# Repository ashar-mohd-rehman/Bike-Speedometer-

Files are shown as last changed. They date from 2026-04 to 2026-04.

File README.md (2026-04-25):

# Bike-Speedometer-
A digital speedometer for my mtb based on XIAO esp 32 s3, NEO 6M GPS module and an 1.3 inch OLED display




Let us talk about features 


- It shows the speed of the cycle (mtb)
- Distance covered from the starting point
- Trip timer which shows how long u have been riding for
- Altitude, which shows ur alt from sea level
- Today's Date
- Satellites GPS module is connected to
- And last but not the least. The Battery Percentage

  The main challenge I faced for CAD. I love cad very much but I always screw up I had to make the case two times :( I love cad but cad hates me

  **CASE**
  

  **Wiring Diagram**
  

  **Case With Components**


 pieace. peace whatever idk spelling 

**BOM**

LINK - https://docs.google.com/spreadsheets/d/1TzOF5hf8aBWl8qxK7e9dfW4KzLnE9d2bEbTf8p3DWF0/edit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

| Component | Description | Quantity | Unit Price (USD) | Total (USD) | Supplier |
|---|---|---|---|---|---|
| Seeed Studio XIAO ESP32-S3 | Main microcontroller | 1 | $9.66 | $9.66 | Robu.in |
| NEO-6M GPS Module | GPS module for position tracking | 1 | $2.70 | $2.70 | Robu.in |
| 1.3" I2C OLED Display Module | SSD1306 128x64 display | 1 | $2.90 | $2.90 | Robu.in |
| Molicel INR-18650-M35A | 3.6V 3500mAh Li-ion battery | 1 | $4.29 | $4.29 | Robu.in |
| MTS-101R Miniature Toggle Switch | SPST 2-pin power switch | 2 | $0.39 | $0.77 | Robu.in |
| 10kΩ 0.25W Metal Film Resistor | For voltage divider circuit | 10 | $0.003 | $0.03 | Robu.in |
| 24AWG Single Core Teflon Wire | Black hookup wire | 1m | $0.19 | $0.19 | Robu.in |
| M5x8mm Brass Heat-Set Inserts | For handlebar clamp mounting | 25 | $0.06 | $1.62 | Robu.in |
| M3x4mm Brass Heat-Set Inserts | For case assembly screws | 25 | $0.04 | $0.96 | Robu.in |
| Fog Lamp Clamp | Handlebar mounting clamp | 2 | $1.52 | $3.04 | Amazon |
| Allen Key Set | Allen keys | 1 | $2.57 | $2.57 | Robu.in |
| | | | **Total:** | **$35** | |

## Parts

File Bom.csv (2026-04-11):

Name | Purpose | Quantity | Total Cost (USD) | Link | Distributor
Fog Lamp Clamp | To clamp speedometer to bike | 2 | 3.04 | https://www.amazon.in/ELTRON-TURBO-Universal-Lamp-Clamp/dp/B0C9WVTJDK?s=automotive | Amazon
M5x8 mm Brass Heat set Threaded Round Insert Nut | To connect the speedometer with bike | 25 | 1.62 | https://robu.in/product/m5-x-8-mm-brass-heat-set-threaded-round-insert-nut-25-pcs/ | Robu.in
M3x4 mm Brass Heat Set Threaded Round Insert Nut | To screw top case to bottom | 25 | 0.96 | https://robu.in/product/m3-x-4-mm-brass-heat-set-knurl-threaded-round-insert-nut-25-pcs/ | Robu.in
24AWG Single core teflon wire | To make connections | 2 | 0.38 | https://robu.in/product/24awg-single-core-teflon-wire-black/ | Robu.in
10k Ohm 0.25W Metal Film Resistor | Volatge divider to check how much battery is left | 10 | 0.03 | https://robu.in/product/10k-ohm-0-25w-metal-film-resistor-pack-of-100/ | Robu.in
MTS-101R-Miniature Toggle Switch-2Pin | To switch on/off the speedometer when not in use | 2 | 0.77 | https://robu.in/product/mts-101r-miniature-toggle-switch-2pinon-off/ | Robu.in
Molicel A Grade INR-18650-M35A 3.6V 3500mAh 3C Li-ion Battery | Battery, To provide power to components | 1 | 4.29 | https://robu.in/product/molicel-inr-18650-m35a-3-6v-3500mah-3c-li-ion-battery/ | Robu.in
NEO-6M GPS Module | Global Positioning System Module. It measures speed using latitude and longitude data by connecting to various sattelites | 1 | 2.70 | https://robu.in/product/neo-6m-gps-module-with-eprom-normal-quality/ | Robu.in
1.3 Inch I2C OLED Display Module | To show speed, time, distance, and other various telemetry | 1 | 2.90 | https://robu.in/product/1-3-inch-i2c-oled-display-module-4-pin-white/ | Robu.in
Seeed Studio XIAO ESP32-S3 | MCU, It is the brain of my speedometer | 1 | 9.66 | https://robocraze.com/products/seeed-studio-xiao-esp32-s3-development-board-supports-wi-fi-bluetooth-5-0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 | Robocraze

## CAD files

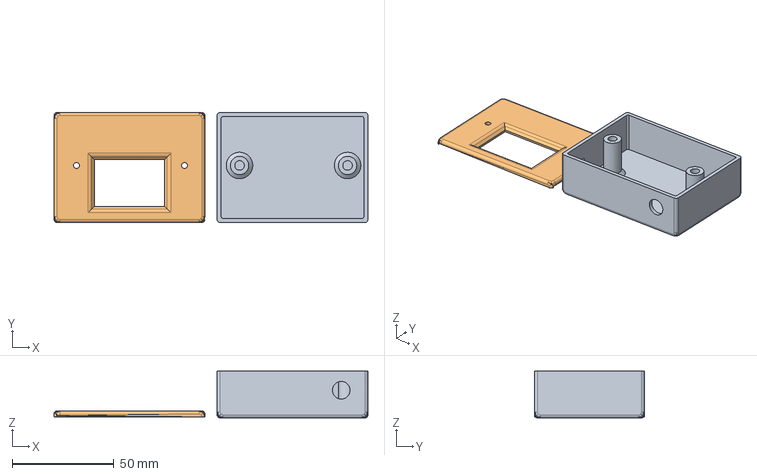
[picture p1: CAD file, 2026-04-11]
CAD/Case.step
154.0 x 54.0 x 23.0 mm

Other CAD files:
CAD/Case.f3d

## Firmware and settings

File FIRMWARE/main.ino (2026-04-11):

/*
 * GPS Bike Speedometer for XIAO ESP32-S3
 * Hardware:
 * - XIAO ESP32-S3
 * - NEO-6M GPS Module (UART)
 * - SSD1306 OLED 128x64 (I2C)
 * - 18650 Li-ion battery with voltage divider
 * 
 * Connections:
 * GPS: TX->GPIO7(RX), RX->GPIO6(TX), VCC->3.3V, GND->GND
 * OLED: SCL->GPIO6, SDA->GPIO5, VCC->3.3V, GND->GND
 * Battery: Through switch to BAT pin, voltage divider to GPIO1
 */

#include <Wire.h>
#include <Adafruit_GFX.h>
#include <Adafruit_SSD1306.h>
#include <TinyGPSPlus.h>
#include <HardwareSerial.h>

// Display settings
#define SCREEN_WIDTH 128
#define SCREEN_HEIGHT 64
#define OLED_RESET -1
#define SCREEN_ADDRESS 0x3C

// Pin definitions
#define GPS_RX 7   // GPS TX connects here
#define GPS_TX 6   // GPS RX connects here
#define VBAT_PIN 1 // Battery voltage sensing (ADC)
#define SDA_PIN 5  // I2C SDA
#define SCL_PIN 6  // I2C SCL

// GPS UART (using Serial1)
HardwareSerial GPS_Serial(1);

// Objects
Adafruit_SSD1306 display(SCREEN_WIDTH, SCREEN_HEIGHT, &Wire, OLED_RESET);
TinyGPSPlus gps;

// Variables
float currentSpeed = 0.0;
float tripDistance = 0.0;
float maxSpeed = 0.0;
unsigned long tripStartTime = 0;
unsigned long elapsedTime = 0;
int batteryPercent = 0;
int satellites = 0;
float altitude = 0.0;
bool gpsValid = false;

// Previous position for distance calculation
double prevLat = 0.0;
double prevLon = 0.0;
bool firstFix = true;

void setup() {
  Serial.begin(115200);
  
  // Initialize I2C with custom pins
  Wire.begin(SDA_PIN, SCL_PIN);
  
  // Initialize display
  if(!display.begin(SSD1306_SWITCHCAPVCC, SCREEN_ADDRESS)) {
    Serial.println(F("SSD1306 allocation failed"));
    for(;;);
  }
  
  display.clearDisplay();
  display.setTextColor(SSD1306_WHITE);
  display.setCursor(0, 20);
  display.setTextSize(2);
  display.println(F("GPS BIKE"));
  display.setTextSize(1);
  display.setCursor(0, 45);
  display.println(F("Initializing..."));
  display.display();
  delay(2000);
  
  // Initialize GPS
  GPS_Serial.begin(9600, SERIAL_8N1, GPS_RX, GPS_TX);
  
  // Initialize trip timer
  tripStartTime = millis();
  
  Serial.println(F("GPS Bike Speedometer Started!"));
}

void loop() {
  // Read GPS data
  while (GPS_Serial.available() > 0) {
    char c = GPS_Serial.read();
    gps.encode(c);
  }
  
  // Update GPS data if valid
  if (gps.location.isUpdated()) {
    gpsValid = true;
    
    // Get current speed (km/h)
    currentSpeed = gps.speed.kmph();
    
    // Update max speed
    if (currentSpeed > maxSpeed) {
      maxSpeed = currentSpeed;
    }
    
    // Calculate trip distance
    if (gps.location.isValid()) {
      double lat = gps.location.lat();
      double lon = gps.location.lng();
      
      if (!firstFix && prevLat != 0.0 && prevLon != 0.0) {
        // Calculate distance between current and previous position
        double distKm = TinyGPSPlus::distanceBetween(prevLat, prevLon, lat, lon) / 1000.0;
        
        // Only add if speed > 1 km/h (filter out GPS drift when stationary)
        if (currentSpeed > 1.0 && distKm < 0.5) { // Max 500m between updates (sanity check)
          tripDistance += distKm;
        }
      }
      
      prevLat = lat;
      prevLon = lon;
      firstFix = false;
    }
    
    // Get altitude
    if (gps.altitude.isValid()) {
      altitude = gps.altitude.meters();
    }
  }
  
  // Get satellite count
  if (gps.satellites.isUpdated()) {
    satellites = gps.satellites.value();
  }
  
  // Update elapsed time
  elapsedTime = (millis() - tripStartTime) / 1000; // seconds
  
  // Read battery level
  batteryPercent = getBatteryPercent();
  
  // Update display
  updateDisplay();
  
  delay(500); // Update every 500ms
}

int getBatteryPercent() {
  // Read ADC (average of 10 samples)
  int sum = 0;
  for(int i = 0; i < 10; i++) {
    sum += analogRead(VBAT_PIN);
    delay(10);
  }
  float avg = sum / 10.0;
  
  // ESP32-S3 ADC: 0-4095 = 0-3.3V
  // Voltage divider: multiply by 2
  float voltage = (avg / 4095.0) * 3.3 * 2.0;
  
  // 18650 range: 4.2V (100%) to 3.0V (0%)
  if(voltage >= 4.2) return 100;
  if(voltage <= 3.0) return 0;
  
  int percent = ((voltage - 3.0) / (4.2 - 3.0)) * 100;
  return constrain(percent, 0, 100);
}

void updateDisplay() {
  display.clearDisplay();
  
  // --- LEFT SIDE ---
  
  // SPEED label (top left)
  display.setTextSize(1);
  display.setCursor(0, 0);
  display.print(F("SPEED"));
  
  // Current speed (BIG)
  display.setTextSize(3);
  display.setCursor(0, 12);
  if (gpsValid && currentSpeed > 0) {
    display.print(currentSpeed, 1);
  } else {
    display.print(F("--"));
  }
  
  // KM unit
  display.setTextSize(1);
  display.setCursor(90, 20);
  display.print(F("KM"));
  display.setCursor(90, 30);
  display.print(F("H"));
  
  // Distance
  display.setTextSize(1);
  display.setCursor(0, 42);
  display.print(F("Distance"));
  display.setTextSize(1);
  display.setCursor(0, 52);
  display.print(tripDistance, 2);
  display.print(F(" KM"));
  
  // Dashed divider line (vertical)
  for(int y = 0; y < 64; y += 4) {
    display.drawPixel(84, y, SSD1306_WHITE);
    display.drawPixel(84, y+1, SSD1306_WHITE);
  }
  
  // Horizontal dashed line below distance
  for(int x = 0; x < 84; x += 4) {
    display.drawPixel(x, 47, SSD1306_WHITE);
    display.drawPixel(x+1, 47, SSD1306_WHITE);
  }
  
  // --- RIGHT SIDE ---
  
  // Battery icon and percentage (top right)
  drawBattery(105, 0, batteryPercent);
  display.setTextSize(1);
  display.setCursor(88, 2);
  display.print(batteryPercent);
  display.print(F("%"));
  
  // Date
  display.setTextSize(1);
  display.setCursor(88, 14);
  display.print(F("Date"));
  display.setCursor(88, 24);
  if (gps.date.isValid()) {
    display.print(gps.date.day());
    display.print(F("-"));
    display.print(gps.date.month());
    display.print(F("-"));
    display.print(gps.date.year() % 100); // Last 2 digits of year
  } else {
    display.print(F("--"));
  }
  
  // Altitude
  display.setCursor(88, 34);
  display.print(F("Alt"));
  display.setCursor(88, 44);
  if (gps.altitude.isValid()) {
    display.print((int)altitude);
    display.print(F("m"));
  } else {
    display.print(F("--"));
  }
  
  // GPS Satellites
  display.setCursor(88, 54);
  display.print(F("GPS:"));
  display.print(satellites);
  
  // TIME (bottom left)
  display.setTextSize(1);
  display.setCursor(0, 56);
  display.print(F("TIME-"));
  
  // Format elapsed time as HH:MM
  int hours = elapsedTime / 3600;
  int minutes = (elapsedTime % 3600) / 60;
  int seconds = elapsedTime % 60;
  
  if (hours < 10) display.print(F("0"));
  display.print(hours);
  display.print(F(":"));
  if (minutes < 10) display.print(F("0"));
  display.print(minutes);
  
  display.display();
}

void drawBattery(int x, int y, int percent) {
  // Battery body (16x8 pixels)
  display.drawRect(x, y+2, 16, 8, SSD1306_WHITE);
  
  // Battery tip
  display.fillRect(x+16, y+4, 2, 4, SSD1306_WHITE);
  
  // Fill level (based on percentage)
  int fillWidth = map(percent, 0, 100, 0, 14);
  if (fillWidth > 0) {
    display.fillRect(x+1, y+3, fillWidth, 6, SSD1306_WHITE);
  }
  
  // Low battery warning (invert if < 20%)
  if (percent < 20) {
    display.fillRect(x, y+2, 16, 8, SSD1306_INVERSE);
  }
}
